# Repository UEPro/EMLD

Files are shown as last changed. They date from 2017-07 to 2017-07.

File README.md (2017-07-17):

# EMLD
Electromagnetic Listening Device<br />

This PCB was designed for a Workshop in Germany, thus the documentation is in German. Contact me if you need a translation (Contact info in folder "Documentation", file "Anleitung_EMLD")

<b>AKF-WORKSHOP:</b></n>

Hallo ihr Lieben, ich hoffe ihr hattet alle ein tolles Festival und seid gut Heim gekommen. :)

Vielen Dank, dass ihr beim Workshop mitgemacht habt. Es hat mir riesigen Spaß gemacht, mit euch zu Arbeiten und ich hoffe auch ihr hattet Freude am basteln.

Dieses Archiv ist noch ziemlich leer, ich werde es aber diese Woche füllen. Wenn ihr ab Montag wieder kommt, sollte alles hier sein.

Solltet ihr irgendwelche Fragen oder Probleme haben, schreibt mir einfach über github oder schickt mir eine E-Mail (die Adresse steht in der Anleitung oben im Ordner "Documentation").

Ich werde außerdem eine Facebookseite einrichten, damit ihr mich einfacher kontaktieren könnt. Der Link dazu kommt dann hier her.

Schreibt mir gerne auch für weiteres Feedback und Vorschläge.

Nochmals Danke für die tolle Zeit mit euch und das nette Feedback :) Ich hoffe man sieht sich wieder.

Downloadanleitung:<br />
-Einzelne Datei: Rechtsklick auf die Datei → "Ziel speichern unter" anklicken<br />
-Ganzes Archiv: oben rechts den grünen Knopf "Clone or download" anklicken → "Download as ZIP" anklicken → ZIP Archiv entpacken

This project is based on LOM-Instrument's <a href="https://github.com/LOM-instruments/Elektrosluch-3">Electrosluch-3</a> and was adapted for the AKF festival's synthesizer workshop.

<br /><span xmlns:dct="http://purl.org/dc/terms/" property="dct:title">Electromagnetic Listening Device</span> by <a xmlns:cc="http://creativecommons.org/ns#" href="https://github.com/UEPro/" property="cc:attributionName" rel="cc:attributionURL">Useless Electronics Projects</a> is licensed under a <a rel="license" href="http://creativecommons.org/licenses/by-sa/4.0/">Creative Commons Attribution-ShareAlike 4.0 International License</a>.<br />

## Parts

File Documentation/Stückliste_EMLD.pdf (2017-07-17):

## ElectroMagneticListeningDevice – Bill of Materials (github.com/UEPro/EMLD)

Type | Manufacturer | Model | Specification | Package | Value | N | Part-Nr | Designators
Resistor | Royal Ohm | Metal film resistor | 0,6W; 250V; 50ppm/K | THT-axial | 1 kΩ ±1% | 4 MF006FF1001A50 | | R1-2, R5-6
Resistor | Royal Ohm | Metal film resistor | 0,6W; 250V; 50ppm/K | THT-axial | 10 kΩ ±1% | 1 MF006FF1002A50 | | R10
Resistor | Royal Ohm | Metal film resistor | 0,6W; 250V; 50ppm/K | THT-axial | 47 kΩ ±1% | 4 MF006FF1203A50 | | R3-4, R7-8
Resistor | Royal Ohm | Metal film resistor | 0,6W; 250V; 50ppm/K | THT-axial | 100 kΩ ±1% | 2 MF006FF1003A50 | | R11-12
Resistor | Royal Ohm | Metal film resistor | 125mW; 150V= | SMD-0805 | 100 kΩ ±1% | 1 0805S8F1003T5E | | R9
Potentiometer | Alps | R12L | log. stereo | THT-radial | 10 kΩ | 1 RK12L12C0A0G | | VR1
Capacitor | SR Passives | Ceramic Disk | 50V | THT 100mil | 47 pF ±10% | 4 | | C7-10
Capacitor | Kemet | MLCC | 50V; X7R | THT 100mil | 100 nF ±10% | 4 C320C104K5R5TA | | C1-4
Capacitor | Wima | Polyester Capacitor | 63VAC; 100VDC | THT 200mil | 2,2 µF ±10% | 4 | MKS2D042201N00KO 00 | C5-6, C11-12
Capacitor | Nichicon | Electrolytic Capacitor | 16V; ø6,3mm | THT-radial | 220 µF ±20% | 2 UVZ1C221MED | | C13-14
Inductor | Ferrocore | | 110mA | THT-5mm | 22 mH ±10% | 2 | | L1-2
Diode | Diotec | ZMM4.7 | Z-Diode; 0,5W | MiniMELF | 4,7 V | 1 ZMM4.7 | | D1
Diode | Optosupply | LED | cyan 3mm | THT-radial | | 1 OSC34L3131A | | D2
Transistor | Fairchild | FDN304 | P-Ch. MOSFET | SOT-23 | | 1 FDN304P | | Q1
IC | TI | NE5532 | | DIP-8 | | 2 NE5532P | | U1-2
Switch | Generic | | SPDT Slide Switch | THT-radial | | 1 | | S1
Connector | Generic | Pin header | 1x2pin | THT 100mil | | 1 | | J1
Connector | Generic | Pin header connector | 1x2pin | THT 100mil | | 1
Connector | Generic | Crimp Contacts | Female | | | 2
Connector | Lumberg | | Stereo 3,5mm TRS-Jack | THT | | 1 1503 07 | | J2
Connector | Generic | Battery Clip | 9V-Block | | | 1
PCB | | | | | | 1
Case | Gainta | | | | | 1 G1068B
Speaker | NOS | | 8ohm | | | 1
Battery | Duracell | 9V Industrial | 6LR61 | | | 1

NB: These are the parts I have used, mostly because I had them in stock. Other parts with other values/tolerances or from other manufacturers may work just as well or even better.

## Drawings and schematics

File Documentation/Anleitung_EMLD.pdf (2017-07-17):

# Electromagnetic Listening Device

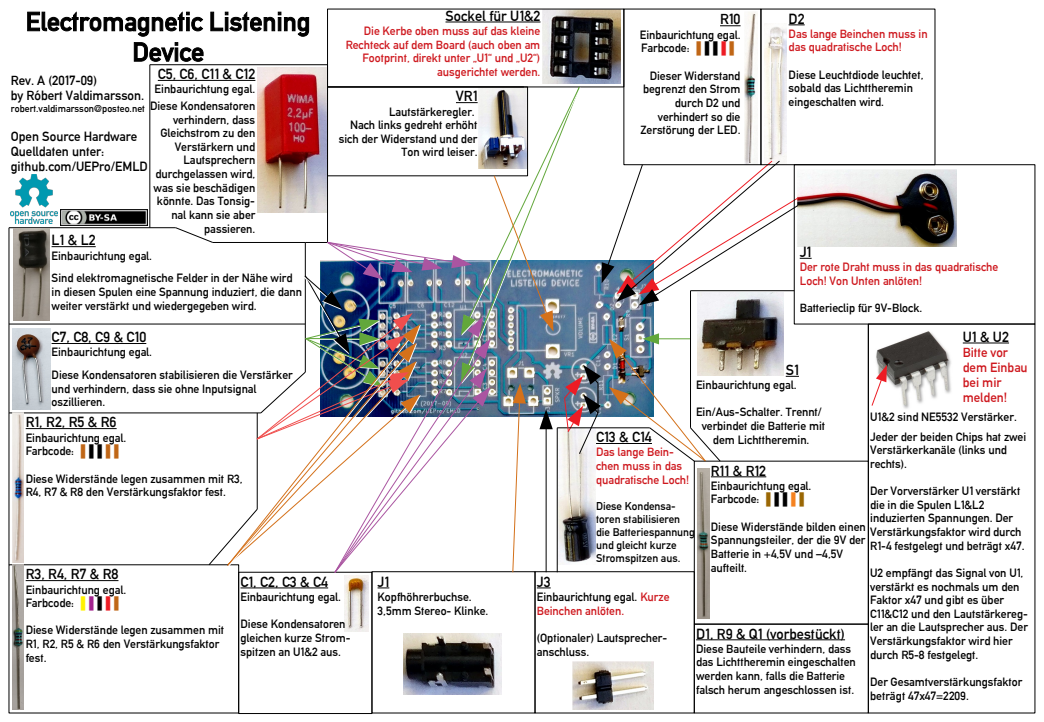
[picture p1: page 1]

Sockel für U1&2 Die Kerbe oben muss auf das kleine Rechteck auf dem Board (auch oben am Footprint, direkt unter „U1“ und „U2“) ausgerichtet werden. | R10 Einbaurichtung egal. Farbcode: ▐▐▐▐▐ Dieser Widerstand begrenzt den Strom durch D2 und verhindert so die Zerstörung der LED. | D2 Das lange Beinchen muss in das quadratische Loch! Diese Leuchtdiode leuchtet, sobald das Lichttheremin eingeschalten wird.

Einbaurichtung egal.
Diese Kondensatoren
verhindern, dass
Gleichstrom zu den
Verstärkern und
Lautsprechern
durchgelassen wird,
was sie beschädigen
könnte. Das Tonsig-
nal kann sie aber
passieren.

Rev. A (2017-09)
by Róbert Valdimarsson.
robert.valdimarsson@posteo.net
Open Source Hardware
Quelldaten unter:
github.com/UEPro/EMLD

VR1 Lautstärkeregler. Nach links gedreht erhöht sich der Widerstand und der Ton wird leiser.

Sind elektromagnetische Felder in der Nähe wird
in diesen Spulen eine Spannung induziert, die dann
weiter verstärkt und wiedergegeben wird.
Diese Kondensatoren stabilisieren die Verstärker
und verhindern, dass sie ohne Inputsignal
oszillieren.
Farbcode: ▐▐▐▐▐

Der rote Draht muss in das quadratische
Loch! Von Unten anlöten!

Ein/Aus-Schalter. Trennt/
verbindet die Batterie mit
dem Lichttheremin.

U1&2 sind NE5532 Verstärker.
Jeder der beiden Chips hat zwei
Verstärkerkanäle (links und
rechts).

Das lange Bein-
chen muss in das
quadratische Loch!

Diese Widerstände legen zusammen mit R3,
R4, R7 & R8 den Verstärkungsfaktor fest.

Der Vorverstärker U1 verstärkt
die in die Spulen L1&L2
induzierten Spannungen. Der
Verstärkungsfaktor wird durch
R1-4 festgelegt und beträgt x47.

Diese Widerstände bilden einen
Spannungsteiler, der die 9V der
Batterie in +4,5V und –4,5V
aufteilt.

U2 empfängt das Signal von U1,
verstärkt es nochmals um den
Faktor x47 und gibt es über
C11&C12 und den Lautstärkereg-
ler an die Lautsprecher aus. Der
Verstärkungsfaktor wird hier
durch R5-8 festgelegt.

Diese Widerstände legen zusammen mit
R1, R2, R5 & R6 den Verstärkungsfaktor
fest.

D1, R9 & Q1 (vorbestückt)
Diese Bauteile verhindern, dass
das Lichttheremin eingeschalten
werden kann, falls die Batterie
falsch herum angeschlossen ist.

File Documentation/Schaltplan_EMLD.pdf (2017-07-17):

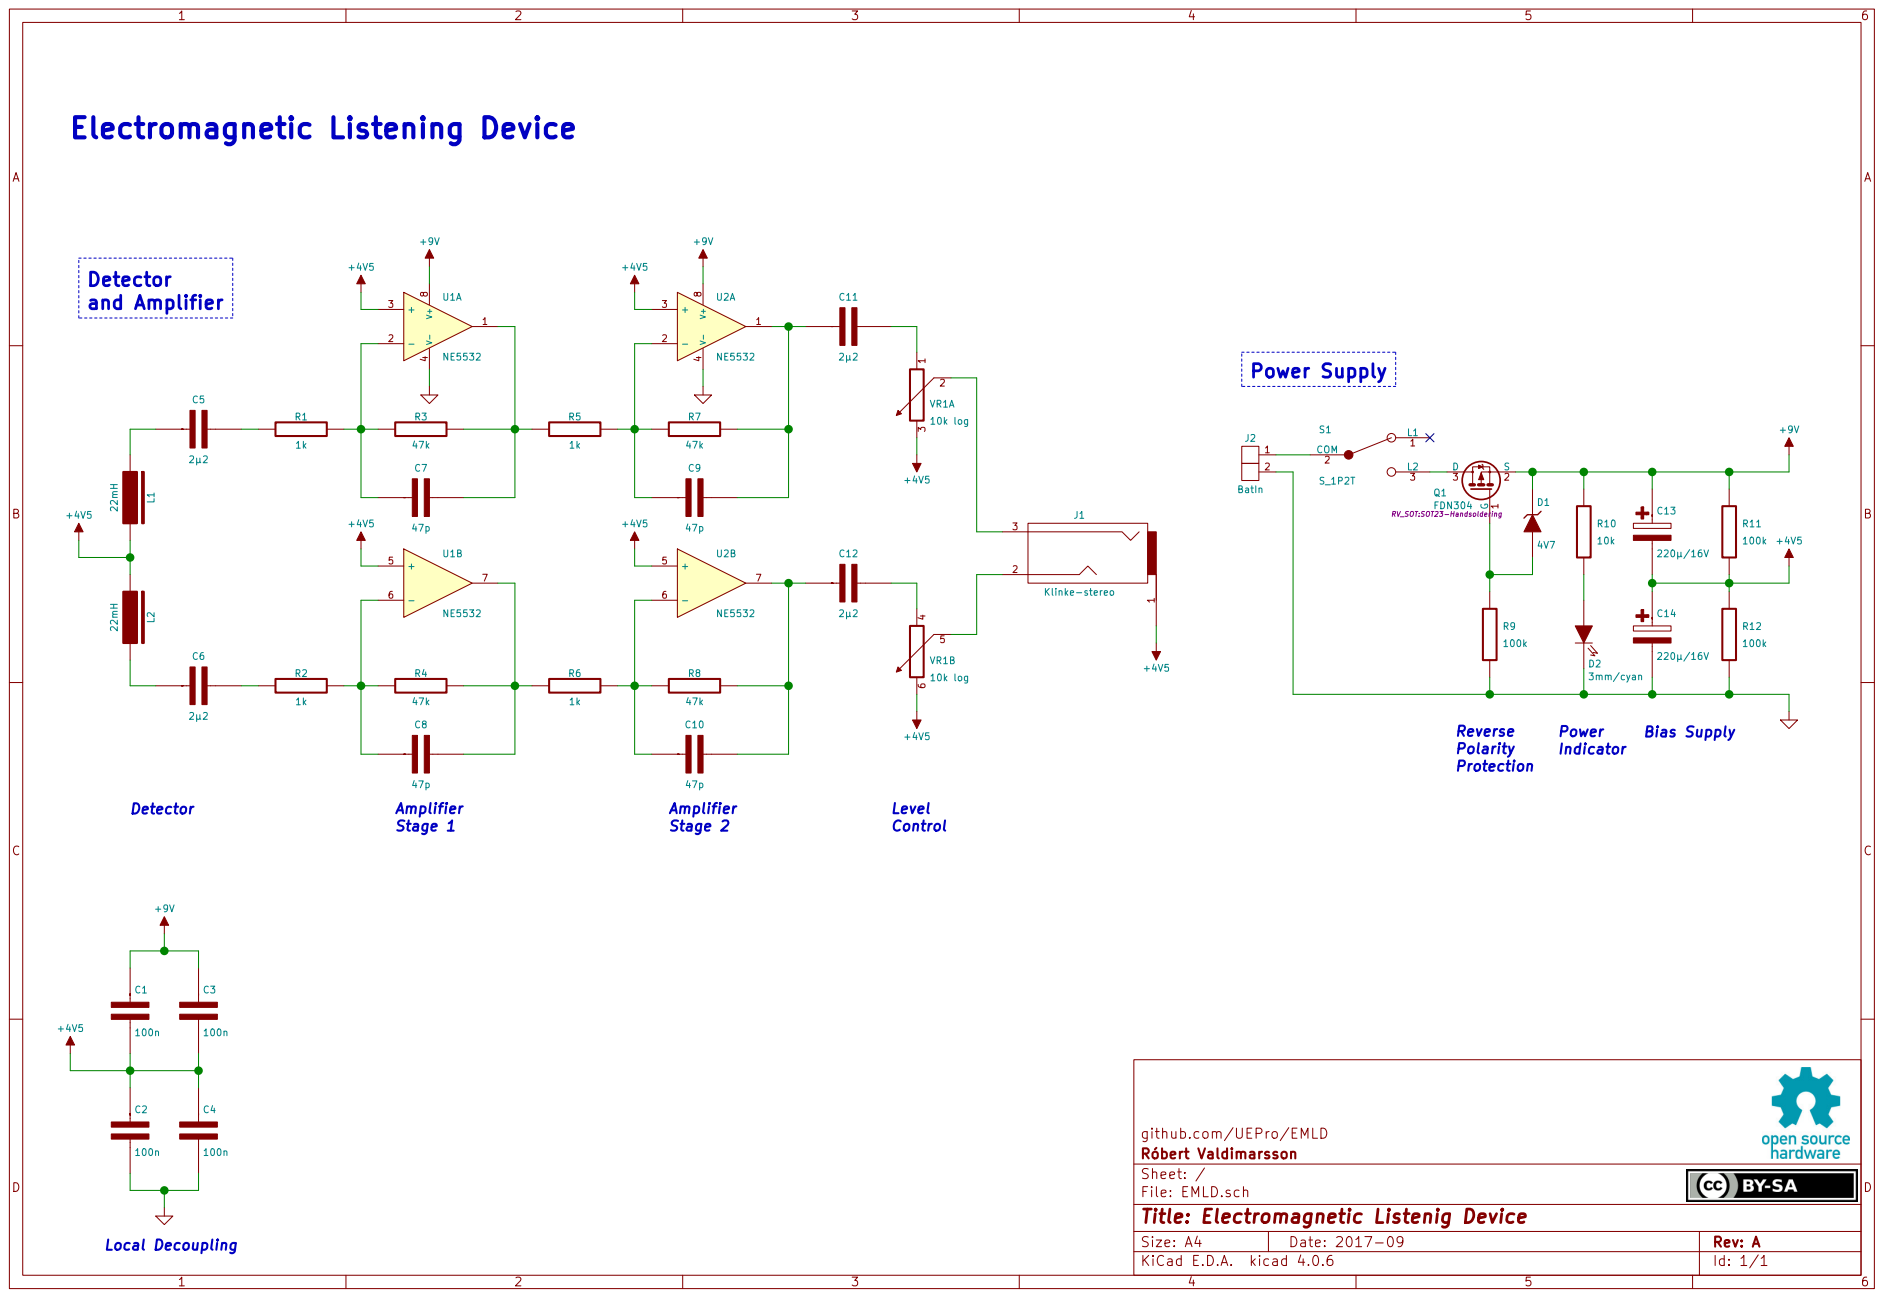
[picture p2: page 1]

github.com/UEPro/EMLD
File: EMLD.sch Sheet: / Róbert Valdimarsson

Id: 1/1 Title: Electromagnetic Listenig Device

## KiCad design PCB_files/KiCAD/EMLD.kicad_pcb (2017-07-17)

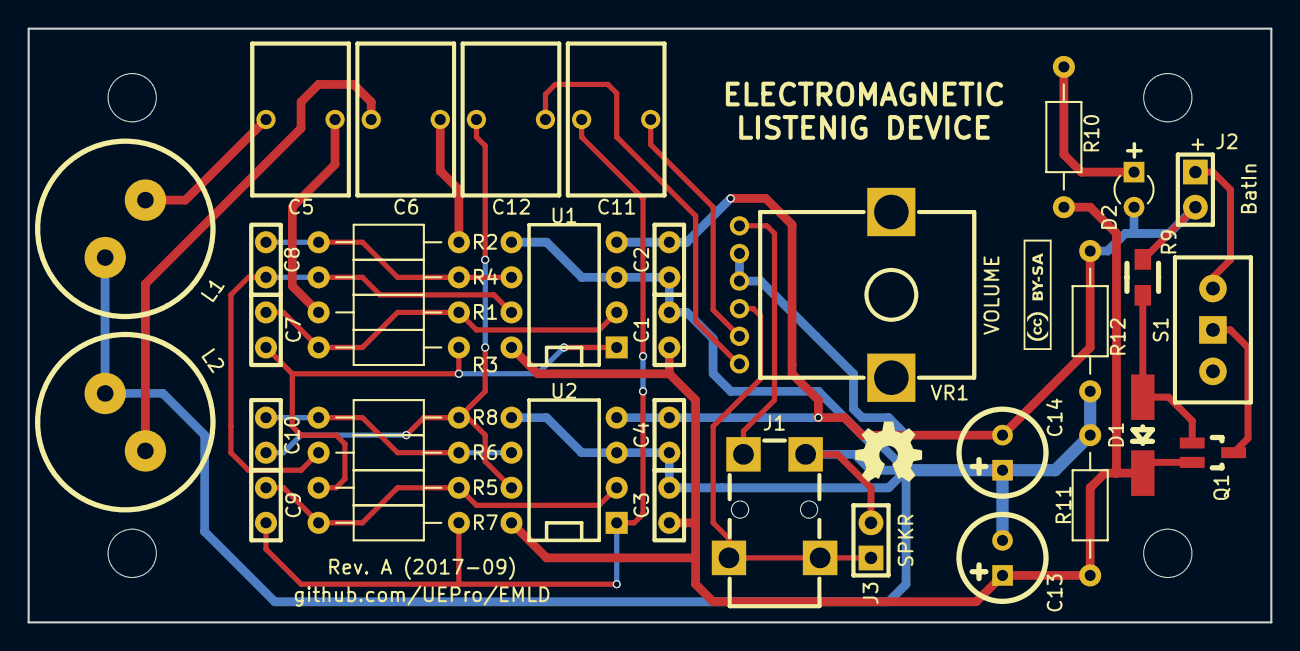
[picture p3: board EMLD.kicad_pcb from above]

Board: 2 copper layers, 90.0 x 43.0 mm, 44 parts (0 on the bottom side), 23 nets.

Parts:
C1, C2, C3, C4: 100n; C_rect-radial-bipolar-100mil-2x5mm
C5, C6, C11, C12: 2µ2; C-Rect_L7_W11_P5
C7, C8, C9, C10: 47p; C_rect-radial-bipolar-100mil-2x5mm
C13, C14: 220µ/16V; C_round-radial-polar-2,5mm-6,3mm
D1: 3V; Diode_MiniMELF-Handsoldering
D2: 3mm/cyan; LED_2pin-3mm
Des*: Val*; MountingHole-3,5mm
Des*#2, Des*#3, Des*#4: Val*; MountingHole-3,5mm
J1: Klinke-stereo; Lumberg-1503-07-Klinke-3,5mm
J2: BatIn; PinArray-100mil-1x2
J3: Val*; PinArray-100mil-1x2
L1, L2: 22mH; C_round-radial-bipolar-5mm-12,5mm
Q1: FDN304; SOT23-Handsoldering
R1, R2, R5, R6: 1k; R_axial_400mil
R3, R4, R7, R8: 120k; R_axial_400mil
R9: 100k; SMD0805-HandSoldering
R10: 10k; R_axial_400mil
R11, R12: 100k; R_axial_400mil
S1: S_1P2T; S-Schiebeschalter_China_SPDT
U1, U2: NE5532; DIP-8_300
VAL: REF; CC-BY-SA_08mm_Fsi
VAL#2: REF; oshw5mm
VR1: 10k log; VR-Alps_R12L_vert

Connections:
+4V5: C1.2, C2.1, C3.2, C4.1, C13.2, C14.1, J1.1, J3.2, L1.2, L2.1, R11.2, R12.1, U1.3, U1.5, U2.3, U2.5, VR1.1, VR1.4
+9V: C1.1, C3.1, C13.1, D1.2, Q1.2, R10.1, R11.1, U1.8, U2.8
GND: C2.2, C4.2, C14.2, D2.2, J2.2, R9.2, R12.2, U1.4, U2.4
unnamed: C5.1, L1.1
unnamed: C5.2, R1.1
unnamed: C6.1, L2.2
unnamed: C6.2, R2.1
unnamed: C7.1, R1.2, R3.1, U1.2
unnamed: C7.2, R3.2, R5.1, U1.1
unnamed: C8.1, R2.2, R4.1, U1.6
unnamed: C8.2, R4.2, R6.1, U1.7
unnamed: C9.1, R5.2, R7.1, U2.2
unnamed: C10.1, R6.2, R8.1, U2.6
unnamed: C10.2, C12.1, R8.2, U2.7
unnamed: C9.2, C11.1, R7.2, U2.1
unnamed: C11.2, VR1.3
unnamed: C12.2, VR1.6
unnamed: D1.1, Q1.1, R9.1
unnamed: D2.1, R10.2
unnamed: J1.2, VR1.5
unnamed: J1.3, J3.1, VR1.2
unnamed: J2.1, S1.3
unnamed: Q1.3, S1.2
